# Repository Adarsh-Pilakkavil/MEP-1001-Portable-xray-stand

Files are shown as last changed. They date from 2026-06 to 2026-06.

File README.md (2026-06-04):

This was a group course project where we had to build a portable xray stand from scratch. We used metal sheets and basic items like lead screws,
to build a fully motorised and functional stand with up and down motion.

If we entered a positive number +x in the serial monitor, then it would move up by x cm distance from the current position. If we entered
a negative number -x, then it would move down by x distance.

I was the team leader of this project with 5 members. I organised meetings, delegated tasks to my team members and even helped them in completing
their tasks.

Final product

Components Used- 
1. Arduino Uno
2. YS-DIV268N-5A motor driver
3. 10.1 kg-cm NEMA 23 motor
4. Arduino IDE
5. Autodesk Fusion
6. Pro-Range A Grade NMC N18650CH 14.8V 2500mAh 3C 4S1P Li-Ion Battery Pack

We had 3-d printed the coupler as we could not find the correct size.

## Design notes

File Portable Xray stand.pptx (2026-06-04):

## Portable Xray stand

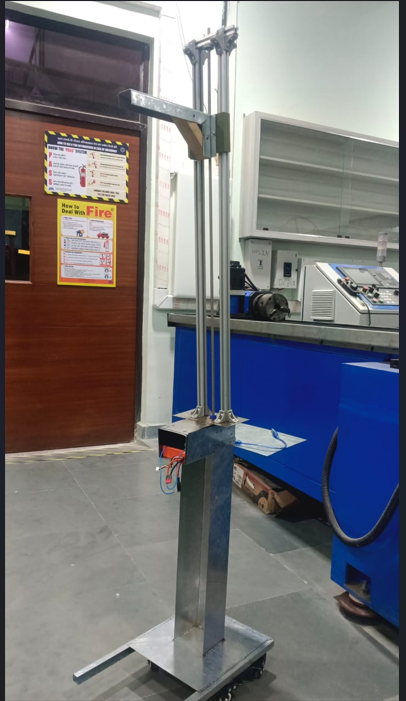
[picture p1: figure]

Team Members-
- Adarsh
- Dhaval
- Anjali
- Krishita
- Ritik

## Shops used

- Sheet metal
- Digital Manafacturing
- Welding
- Fabrication
- CNC
- Woodworking
- 3-d printing

## Individual Contributions

Adarsh | Dhaval | Anjali | Krishita | Ritik
Electronics | Sheet metal | Fabrication | Fabrication | Welding
Sheet metal | Fabrication | Sheet metal | Welding | Fabrication
3-d printing ,Cad models | Welding | Machine shop | Sheet metal | Wood working
Fabrication | Machine shop | 3-d print | Wood working | Sheet metal
Welding | Wood working | CNC | Machine shop | DMF
CNC | Electronics | DMF

## Machines Used

- Sheet metal: Metal sheet cutter, Laser cutter, Sheet bending machine
- Fabrication: hand drill machine, drill
- CNC: Water-jet cutting
- Welding: SMAW, spot welding, Laser welding
- 3-d printing: Creality printer (with fusion software)
- Wood working: Table Saw
- DMF: Arduino Uno, 14.8V battery, Jumper wires, Motor driver

## Innovation

- Our main innovation was using software for input instead of mechanical buttons. It provided greater accuracy and control over the motion of the X-ray head. We can easily shift the position of the X-ray head to any position we wish. It is also easily scalable in the future, as we could change the code and put the stand under our control without any extra expenditure on new components. We also added locking-type wheels to lock the stand in that position.

## Our takeaway and acknowledgement

- We all had fun building this project, and we learned how an idea is converted into a real-life product. One thing we noticed is that as we build a product, some ideas come only when we try to build it. For example, we had difficulty in welding the upper aluminium extrusion and the Mild steel sheet. At that point in time, we got the idea of using screws and an L-bracket.
- I would especially like to thank Mr Pulak Pandey, lab staff, and TAs who showed us constant support and help in providing us with all the material we required.

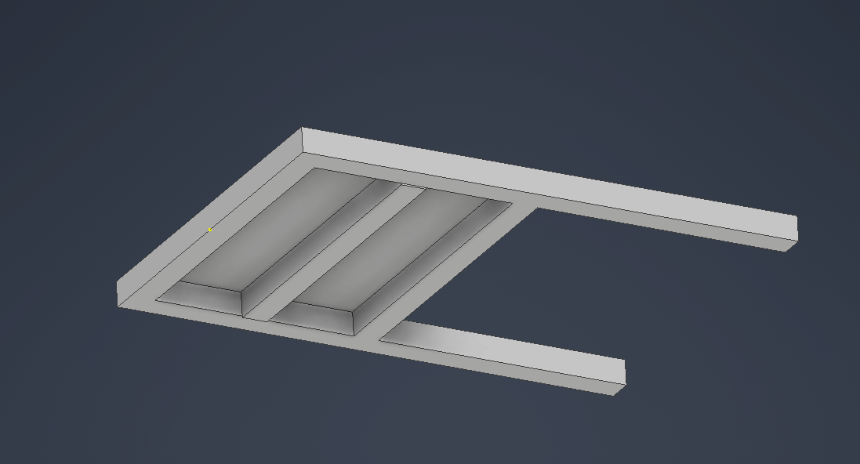
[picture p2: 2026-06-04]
3-d model of base.png

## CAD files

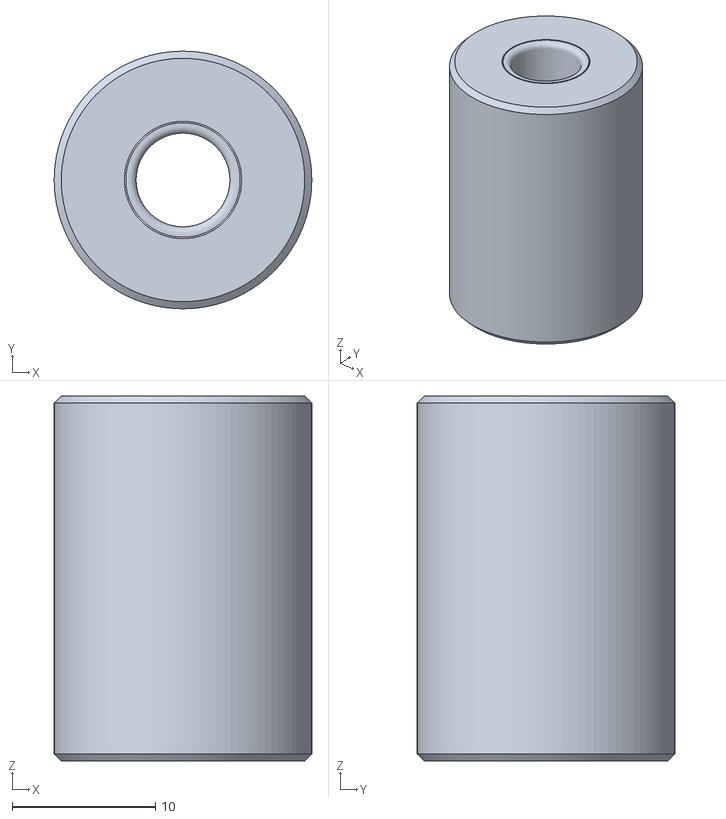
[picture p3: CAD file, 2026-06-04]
coupler.stl
18.0 x 18.0 x 25.5

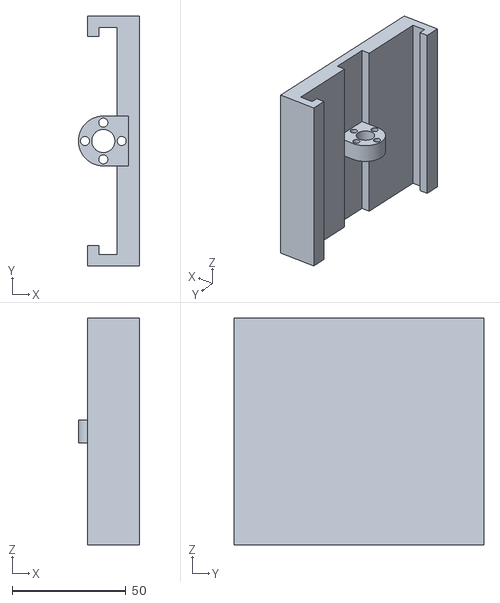
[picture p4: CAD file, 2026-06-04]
Attaching frame.stl
27.0 x 110.0 x 100.0

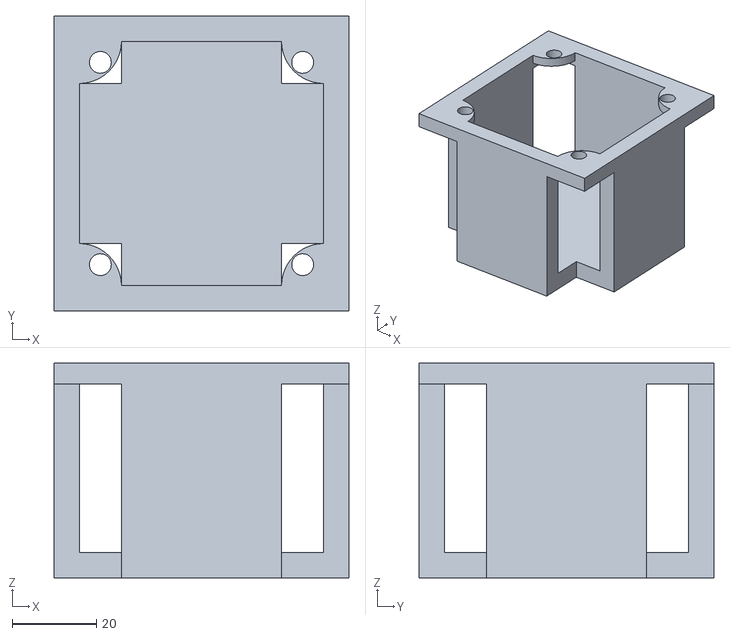
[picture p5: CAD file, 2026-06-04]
Motor Bracket.stl
70.0 x 70.0 x 51.0

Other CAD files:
base.idw

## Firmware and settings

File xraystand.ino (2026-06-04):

#include <AccelStepper.h>

// --- Pin Connections ---
const int stepPin = 9;    // PUL+
const int dirPin = 8;     // DIR+
const int enPin = 7;      // EN+

// --- Calibration ---
// Calculation: 400 steps (1/2 step) / 0.2 cm (lead screw pitch) = 2000 steps per cm.
const float stepsPerCm = 500.0; 

// Define the stepper (1 = Driver interface)
AccelStepper stepper(1, stepPin, dirPin);

void setup() {
  Serial.begin(9600);
  
  pinMode(enPin, OUTPUT);
  digitalWrite(enPin, LOW); // Engage motor to hold the 15kg load

  // --- 11.2V MAX SPEED TUNING ---
  // MaxSpeed: 2500 is likely the limit for 11.2V under load. 
  // If it stalls/buzzes, lower this to 2000.
  stepper.setMaxSpeed(1000);     
  
  // Acceleration: A lower value (500) gives the motor time to 
  // gain momentum with the 15kg weight before hitting top speed.
  stepper.setAcceleration(1000);  
  
  Serial.println("--- 11.2V Max Speed Controller Ready ---");
  Serial.println("Enter CM distance (Positive = Up, Negative = Down):");
}

void loop() {
  if (Serial.available() > 0) {
    float moveDistance = Serial.parseFloat();
    
    if (moveDistance != 0) {
      long targetSteps = moveDistance * stepsPerCm;
      Serial.print("Targeting: ");
      Serial.print(moveDistance);
      Serial.println(" cm at Max Speed.");
      
      stepper.move(targetSteps);
    }
  }

  // Mandatory: keeps the pulses flowing to the driver
  stepper.run();
}
